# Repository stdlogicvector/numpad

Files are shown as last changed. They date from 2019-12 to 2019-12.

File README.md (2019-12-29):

# NumPad

A custom built 5x4 key numpad with encoders and display.

More Info on this [Reddit Thread](https://www.reddit.com/r/MechanicalKeyboards/comments/e81bfg/custom_built_numpad_with_encoders_and_display/)

## Circuit Board

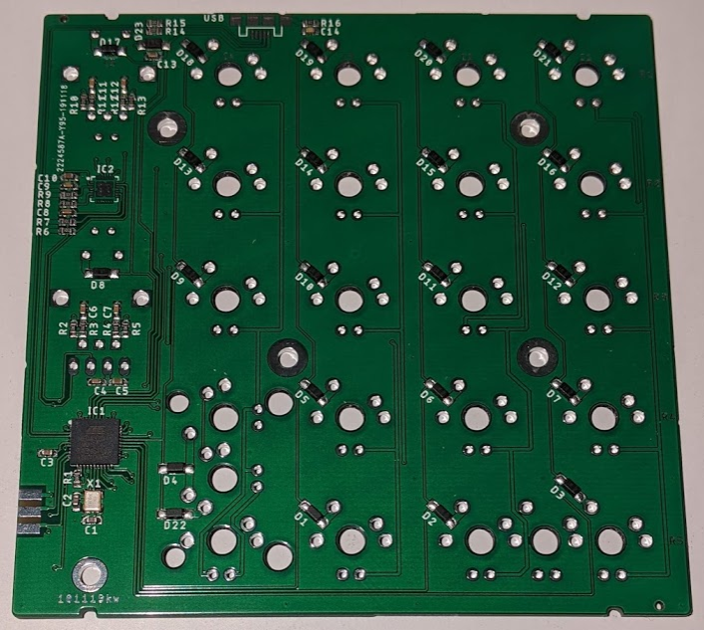
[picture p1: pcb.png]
Populated Circit Board - Bottom Side


The circuit board is designed in Eagle.
For easy manufacturing, the gerber-files and SMT production files are included.

The BOM and SMT placement file (CPL) are formatted for use with JLCPCB.

Apart from the keys, encoders, display, the USB-connector and the LED matrix driver all parts can be populated by JLCPCB.
The schematic contains the LCSC partnumbers in the attributes of each part.

### JLCPCB Configuration

If you want to order PCBs from JLC-PCB with the provided gerber-files,
use the following settings after uploading the zipped gerber folder:

* Layers: 2
* Dimension: 98mm*98mm
* PCB Thickness: 1.6
* PCB Color: Choose what you want
* Impedance: no
* Surface Finish: HASL(with lead) (ENIG is also OK)
* Copper Weight: 1
* Gold Fingers: No
* Material Details: FR4-Standard Tg 130-140C
* Panel By JLCPCB: No
* Flying Probe Test: Fully Test
* Castellated Holes: no
* Different Design: 1
* Remove Order Number: Choose what you want

5 PCBs without assembly cost about 3.60€ or $4.00.

If you want to have the SMT parts populated, choose "SMT Assembly" and select "Bottom Layer".

When asked for the BOM and CPL file, upload the provided files.

Assembly and parts for 5 PCBs costs about 33.30€ or $37.10.

### Keys

All keys compatible with Cherry MX 2 or 3 pin should fit the board.
You can either use a wide 0-key or a normal 0-key and a 00-key.
The Enter-key can also be replaced by two individual keys.

Unfortunately, I forgot to include the option for a standard tall plus-key. Here you have to use two keys.

### Encoders

The encoders a standard rotary encoders, just search ebay/aliexpress/amazon or your local electronics dealer.

### Display

The display is an 0.91" 128x32 SPI OLED module like [this](https://www.ebay.com/itm/312892164528). They are all over ebay and aliexpress.

### Misc Parts

The USB Connector can be found on [Digikey](https://www.digikey.com/short/p12hh9), but you can substitute others with the same pad layout.

The LED Driver is also available on [Digikey](https://www.digikey.com/short/p12hhw).

## QMK Configuration

The folder qmk_config contains the configuration and code to build QMK for the NumPad.
Just put this folder in qmk/keyboards and run

```
make numpad/v1:default
```	
	
## Case

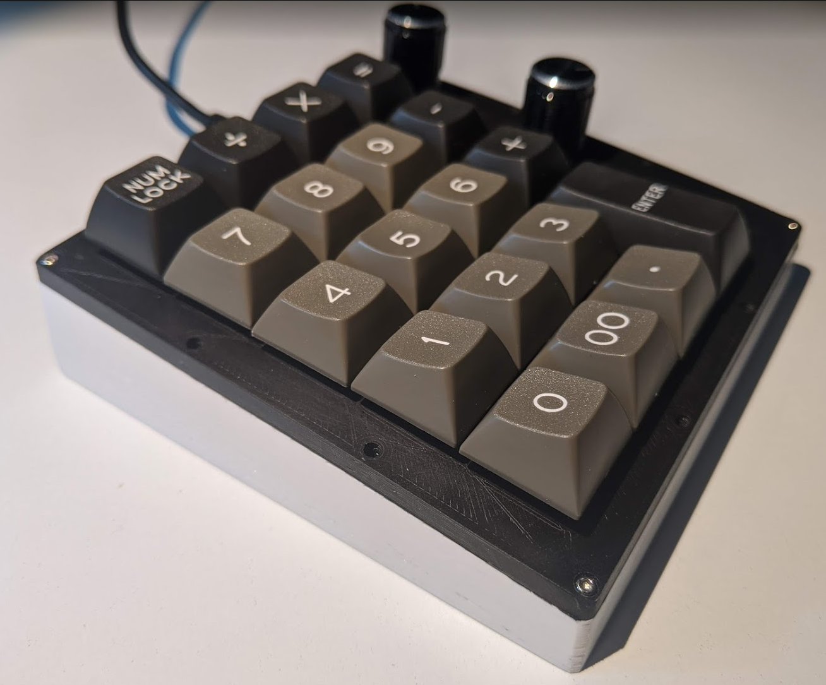
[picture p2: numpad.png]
Numpad with 3D printed case


The case can be 3D printed in two parts.
There are holes for heat-set M3 threaded inserts to hold the PCB and M2 threaded inserts to hold the plate.

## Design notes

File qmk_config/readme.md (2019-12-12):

NumPad
===

NumPad

-=-=-=-=-=-=-=-=-=-=-=-=-=-=-=-

A 18/19/20 key num-pad with 2 rotary encoders and OLED display.

Supports MX switches with LEDs.

Optional "Reset" switch can be used on the PCB.

-=-=-=-=-=-=-=-=-=-=-=-=-=-=-=-

Make example for this keyboard (after setting up your build environment):

    make numpad/v1:default

See [build environment setup](https://docs.qmk.fm/#/getting_started_build_tools) then the [make instructions](https://docs.qmk.fm/#/getting_started_make_guide) for more information.

-=-=-=-=-=-=-=-=-=-=-=-=-=-=-=-

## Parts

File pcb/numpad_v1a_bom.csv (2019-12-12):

Comment | Designator | Footprint | LCSC
1M | R16 | 0603_R | C22935
1N4148W | D1, D2, D3, D4, D5, D6, D7, D8, D9, D10, D11, D12, D13, D14, D15, D16, D17, D18, D19, D20, D21, D22 | SOD-123 | C81598
1u | C3, C5, C10 | 0603_C | C15849
10k | R1, R2, R3, R4, R5, R10, R11, R12, R13 | 0603_R | C25804
10n | C6, C7, C11, C12 | 0603_C | C57112
10n 100V | C14 | 0603_C | C84709
10u | C13 | 0603_C | C19702
12pF | C1, C2 | 0603_C | C38523
16MHz | X1 | SMD-3225_4P | C13738
20k | R6, R7, R8, R9 | 0603_R | C4184
22R | R14, R15 | 0603_R | C23345
100n | C4, C8, C9 | 0603_C | C14663
ATMEGA32U4-MU | IC1 | QFN-44_EP_7x7x0.5P | C112161
B5819W | D23 | SOD-123 | C8598

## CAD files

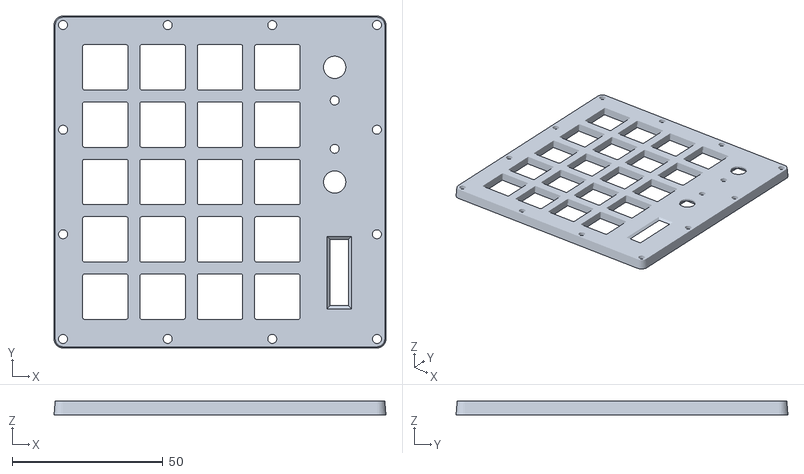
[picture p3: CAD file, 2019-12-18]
case/Cover_4x5.stl
110.0 x 110.0 x 4.50

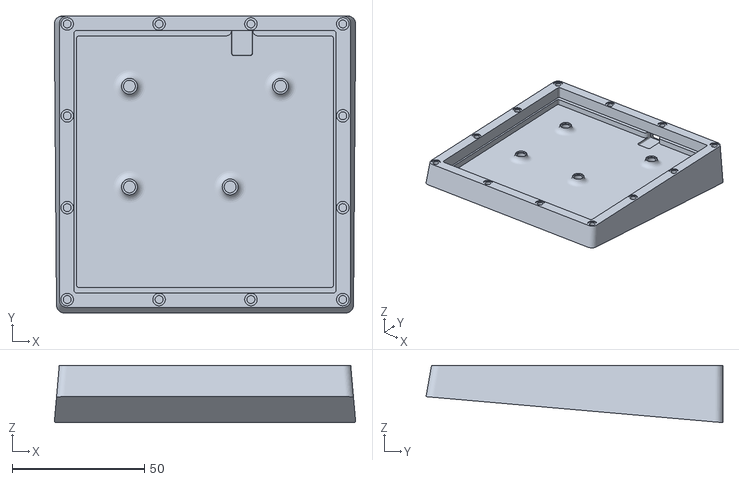
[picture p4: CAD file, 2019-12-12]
case/Case.stl
113.7 x 112.1 x 21.6

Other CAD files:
case/Cover.stl

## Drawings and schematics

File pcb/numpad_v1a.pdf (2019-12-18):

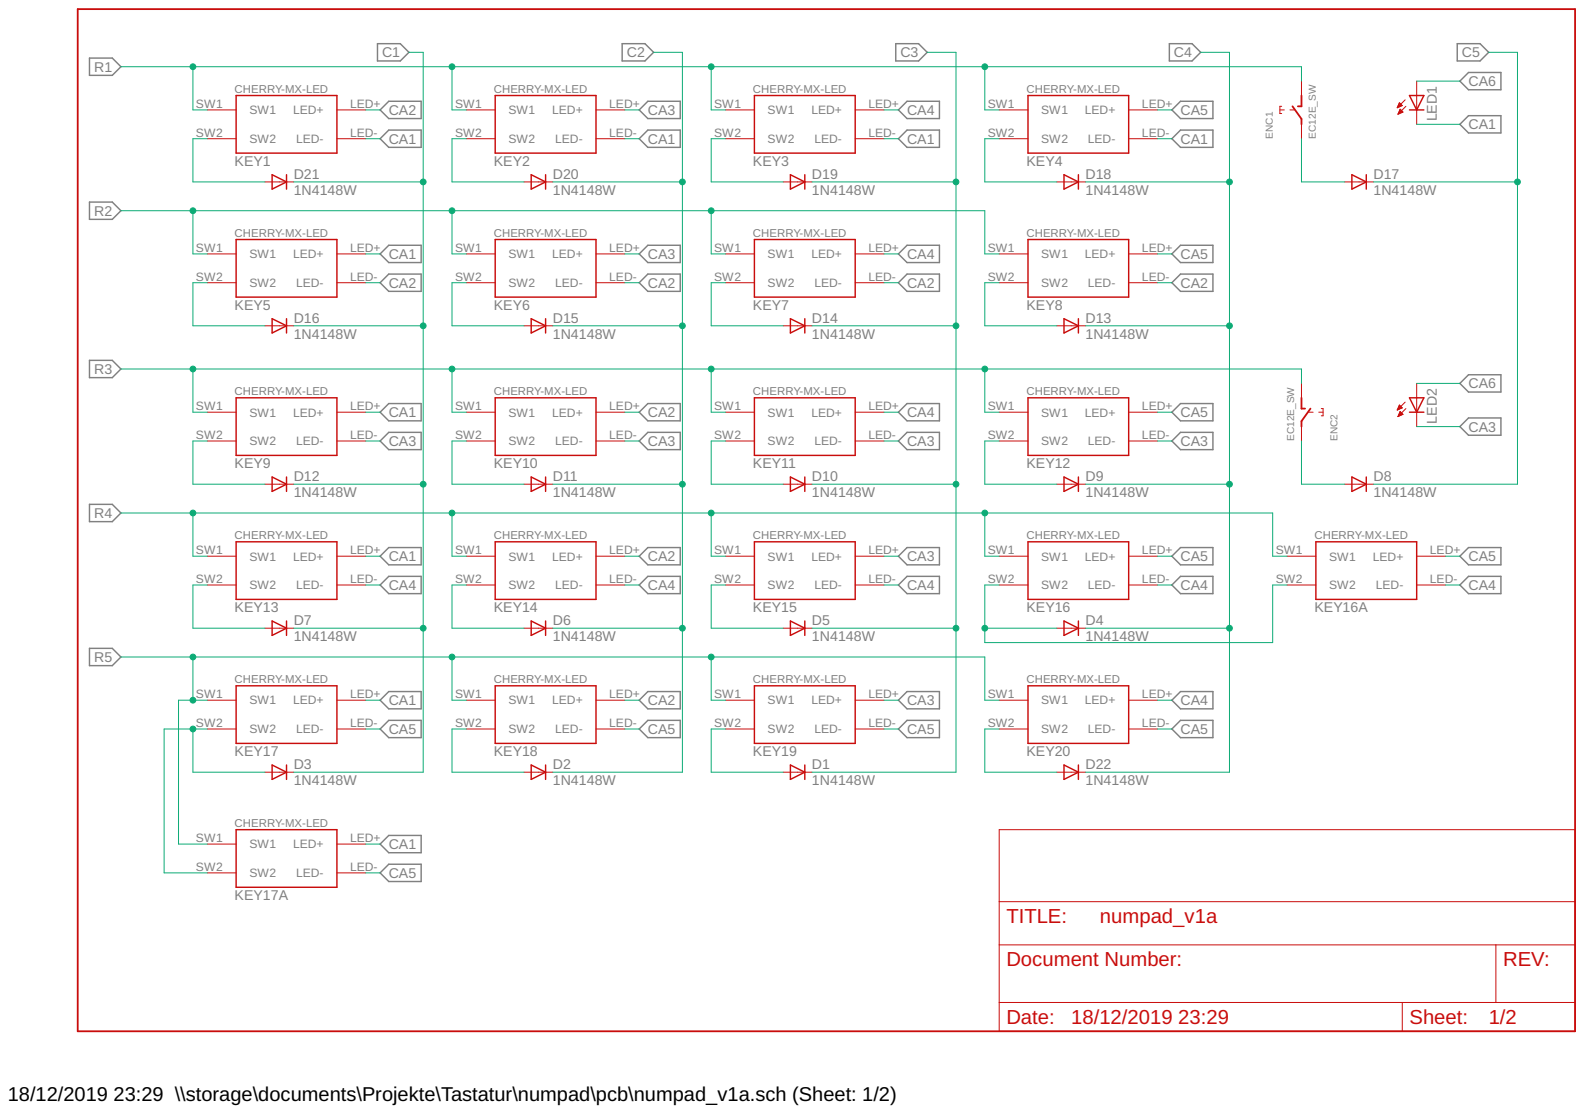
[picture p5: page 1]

Document Number: | REV:

Date: 18/12/2019 23:29 | Sheet: 1/2

18/12/2019 23:29 \\storage\documents\Projekte\Tastatur\numpad\pcb\numpad_v1a.sch (Sheet: 1/2)

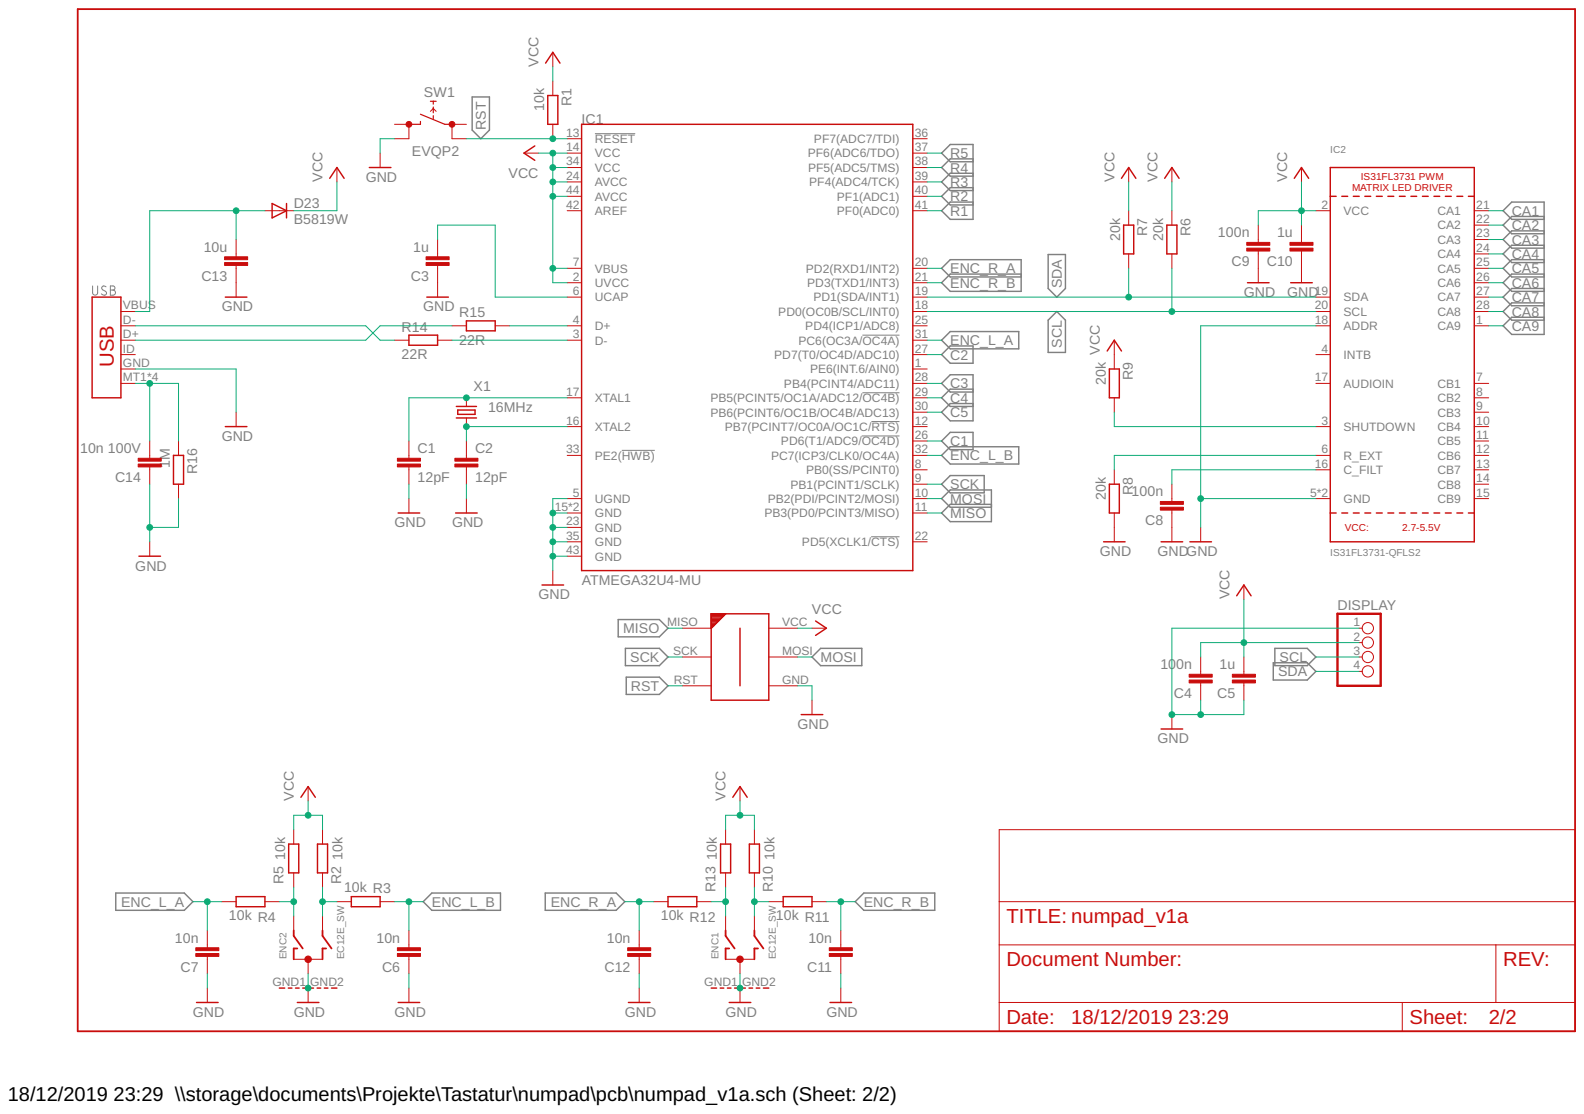
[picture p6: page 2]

18/12/2019 23:29 \\storage\documents\Projekte\Tastatur\numpad\pcb\numpad_v1a.sch (Sheet: 2/2)

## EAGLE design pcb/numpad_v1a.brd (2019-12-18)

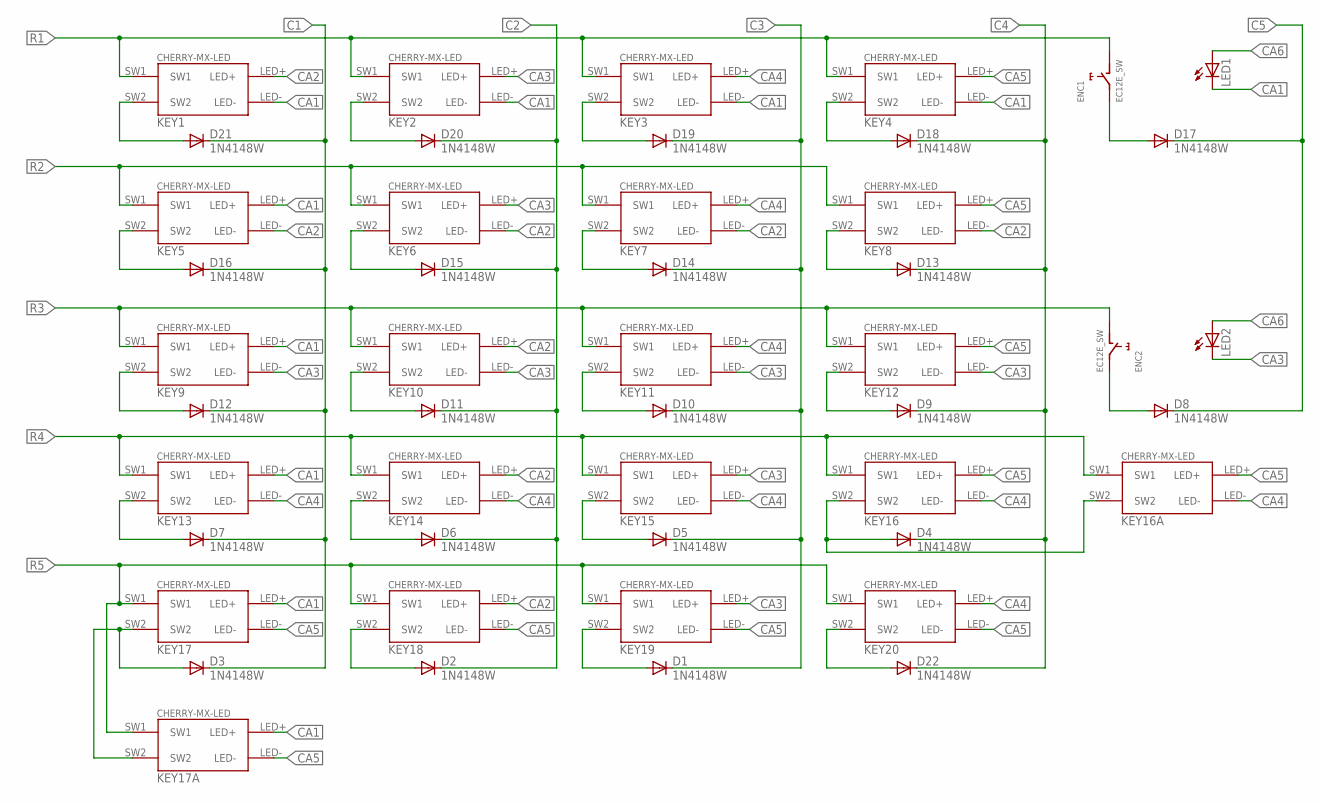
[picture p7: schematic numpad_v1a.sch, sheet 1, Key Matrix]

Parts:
D1, D2, D3, D4, D5, D6, D7, D8, D9, D10, D11, D12, D13, D14, D15, D16, D17, D18, D19, D20, D21, D22: 1N4148W; SOD123; LCSC C81598
ENC1, ENC2: EC12E_SW; ALPS_EC12E_SW
KEY1, KEY2, KEY3, KEY4, KEY5, KEY6, KEY7, KEY8, KEY9, KEY10, KEY11, KEY12, KEY13, KEY14, KEY15, KEY16A, KEY17, KEY18, KEY19, KEY20: CHERRY-MX-LED
KEY16, KEY17A: CHERRY-MX-LED_NOHOLES
LED1, LED2: LED3MM

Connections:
C1: D3.C, D7.C, D12.C, D16.C, D21.C; also elsewhere on the board
C2: D2.C, D6.C, D11.C, D15.C, D20.C; also elsewhere on the board
C3: D1.C, D5.C, D10.C, D14.C, D19.C; also elsewhere on the board
C4: D4.C, D9.C, D13.C, D18.C, D22.C; also elsewhere on the board
C5: D8.C, D17.C; also elsewhere on the board
CA1: KEY1.LED-, KEY2.LED-, KEY3.LED-, KEY4.LED-, KEY5.LED+, KEY9.LED+, KEY13.LED+, KEY17.LED+, KEY17A.LED+, LED1.K (C); also elsewhere on the board
CA2: KEY1.LED+, KEY5.LED-, KEY6.LED-, KEY7.LED-, KEY8.LED-, KEY10.LED+, KEY14.LED+, KEY18.LED+; also elsewhere on the board
CA3: KEY2.LED+, KEY6.LED+, KEY9.LED-, KEY10.LED-, KEY11.LED-, KEY12.LED-, KEY15.LED+, KEY19.LED+, LED2.K (C); also elsewhere on the board
CA4: KEY3.LED+, KEY7.LED+, KEY11.LED+, KEY13.LED-, KEY14.LED-, KEY15.LED-, KEY16.LED-, KEY16A.LED-, KEY20.LED+; also elsewhere on the board
CA5: KEY4.LED+, KEY8.LED+, KEY12.LED+, KEY16.LED+, KEY16A.LED+, KEY17.LED-, KEY17A.LED-, KEY18.LED-, KEY19.LED-, KEY20.LED-; also elsewhere on the board
CA6: LED1.A, LED2.A; also elsewhere on the board
unnamed: D21.A, KEY1.SW2
unnamed: D16.A, KEY5.SW2
unnamed: D12.A, KEY9.SW2
unnamed: D7.A, KEY13.SW2
unnamed: D15.A, KEY6.SW2
unnamed: D20.A, KEY2.SW2
unnamed: D11.A, KEY10.SW2
unnamed: D6.A, KEY14.SW2
unnamed: D5.A, KEY15.SW2
unnamed: D10.A, KEY11.SW2
unnamed: D14.A, KEY7.SW2
unnamed: D19.A, KEY3.SW2
unnamed: D8.A, ENC2.E (2)
unnamed: D17.A, ENC1.E (2)
unnamed: D3.A, KEY17.SW2, KEY17A.SW2
unnamed: D2.A, KEY18.SW2
unnamed: D1.A, KEY19.SW2
unnamed: D4.A, KEY16.SW2, KEY16A.SW2
unnamed: D9.A, KEY12.SW2
unnamed: D13.A, KEY8.SW2
unnamed: D18.A, KEY4.SW2
unnamed: D22.A, KEY20.SW2
R1: ENC1.D (1), KEY1.SW1, KEY2.SW1, KEY3.SW1, KEY4.SW1; also elsewhere on the board
R2: KEY5.SW1, KEY6.SW1, KEY7.SW1, KEY8.SW1; also elsewhere on the board
R3: ENC2.D (1), KEY9.SW1, KEY10.SW1, KEY11.SW1, KEY12.SW1; also elsewhere on the board
R4: KEY13.SW1, KEY14.SW1, KEY15.SW1, KEY16.SW1, KEY16A.SW1; also elsewhere on the board
R5: KEY17.SW1, KEY17A.SW1, KEY18.SW1, KEY19.SW1, KEY20.SW1; also elsewhere on the board

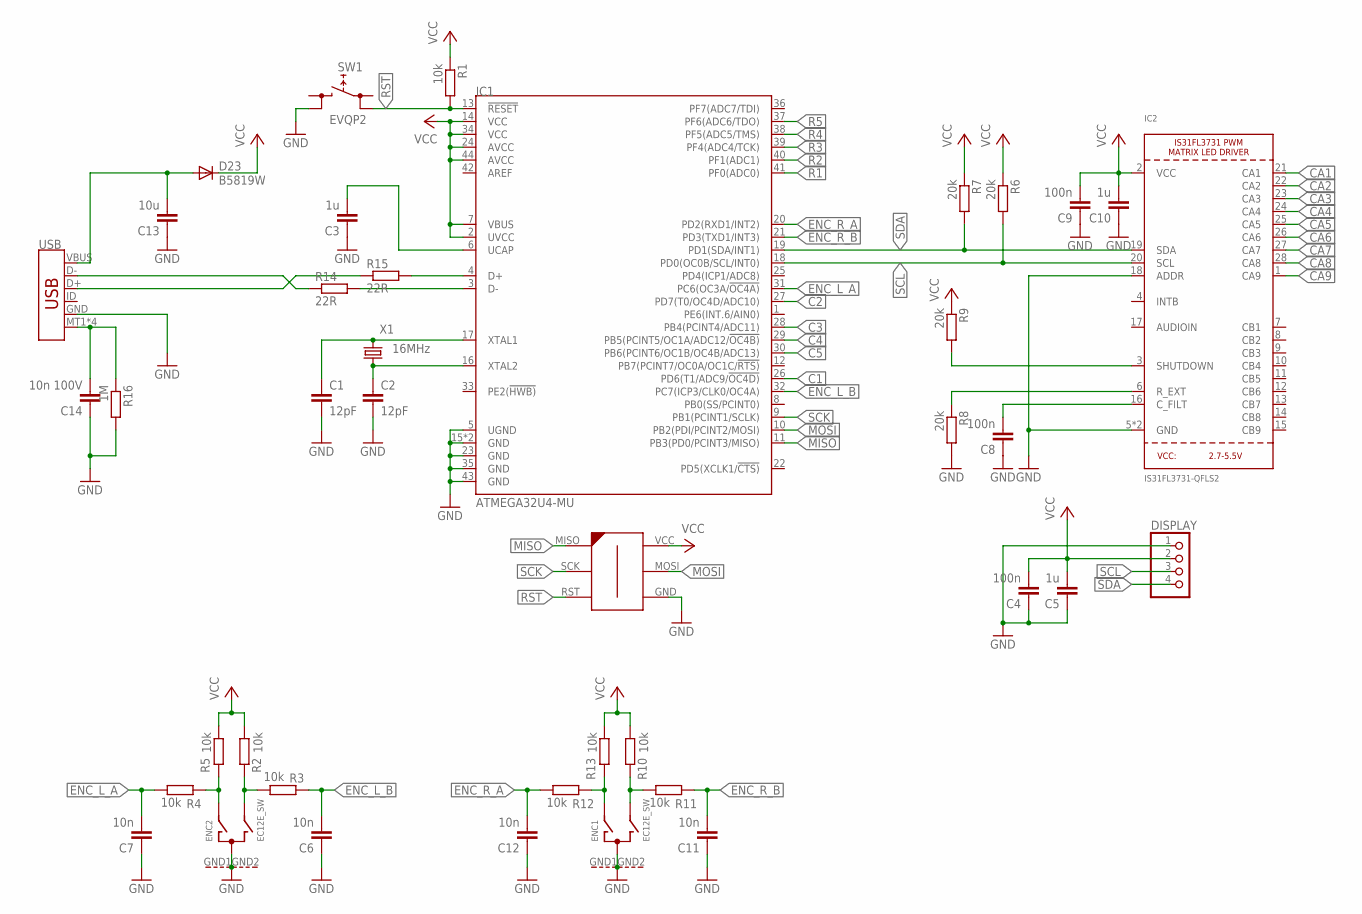
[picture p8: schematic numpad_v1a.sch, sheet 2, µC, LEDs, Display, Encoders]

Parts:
C1, C2: 12pF; C0603; LCSC C38523
C3, C5, C10: 1u; C0603; LCSC C15849
C4, C8, C9: 100n; C0603; LCSC C14663
C6, C7, C11, C12: 10n; C0603; LCSC C57112
C13: 10u; C0603; LCSC C19702
C14: 10n 100V; C0603; LCSC C84709
D23: B5819W; SOD123; LCSC C8598
DISPLAY: PINHD-1X4; 1X04
ENC1, ENC2: EC12E_SW; ALPS_EC12E_SW
IC1: ATMEGA32U4-MU; QFN44G-0.5-7X7MM; LCSC C112161
IC2: IS31FL3731-QFLS2; QFN28_4MM_0.4MM
ISP: AVR-ISP-6-EDGE; 6PAD_ISP
R1, R2, R3, R4, R5, R10, R11, R12, R13: 10k; R0603; LCSC C25804
R6, R7, R8, R9: 20k; R0603; LCSC C4184
R14, R15: 22R; R0603; LCSC C23345
R16: 1M; R0603; LCSC C22935
SW1: EVQP2; FARNELL 2079559
USB: USB_MICRO-B_SMT; USB-MICROB; DIGIKEY 609-4052-1-ND
X1: 16MHz; 3.2X2.5_KX-7; LCSC C13738

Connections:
C1: IC1.26 (PD6(T1/ADC9/!OC4D)); also elsewhere on the board
C2: IC1.27 (PD7(T0/OC4D/ADC10)); also elsewhere on the board
C3: IC1.28 (PB4(PCINT4/ADC11)); also elsewhere on the board
C4: IC1.29 (PB5(PCINT5/OC1A/ADC12/!OC4B)); also elsewhere on the board
C5: IC1.30 (PB6(PCINT6/OC1B/OC4B/ADC13)); also elsewhere on the board
CA1: IC2.21 (CA1); also elsewhere on the board
CA2: IC2.22 (CA2); also elsewhere on the board
CA3: IC2.23 (CA3); also elsewhere on the board
CA4: IC2.24 (CA4); also elsewhere on the board
CA5: IC2.25 (CA5); also elsewhere on the board
CA6: IC2.26 (CA6); also elsewhere on the board
CA7: IC2.27 (CA7)
CA8: IC2.28 (CA8)
CA9: IC2.1 (CA9)
ENC_L_A: C7.2, IC1.31 (PC6(OC3A/!OC4A)), R4.1
ENC_L_B: C6.2, IC1.32 (PC7(ICP3/CLK0/OC4A)), R3.2
ENC_R_A: C12.2, IC1.20 (PD2(RXD1/INT2)), R12.1
ENC_R_B: C11.2, IC1.21 (PD3(TXD1/INT3)), R11.2
GND: C1.2, C2.2, C3.1, C4.1, C5.1, C6.1, C7.1, C8.1, C9.1, C10.1, C11.1, C12.1, C13.1, C14.1, DISPLAY.1, ENC1.C, ENC1.GND1 (G), ENC1.GND2 (G), ENC2.C, ENC2.GND1 (G), ENC2.GND2 (G), IC1.5 (UGND), IC1.15 (GND), IC1.23 (GND), IC1.35 (GND), IC1.43 (GND), IC1.TAB (GND), IC2.5 (GND), IC2.18 (ADDR), IC2.THERMAL (GND), ISP.GND, R8.2, R16.2, SW1.2 (1), USB.GND
MISO: IC1.11 (PB3(PD0/PCINT3/MISO)), ISP.MISO
MOSI: IC1.10 (PB2(PDI/PCINT2/MOSI)), ISP.MOSI
unnamed: IC1.4 (D+), R15.2
unnamed: IC1.3 (D-), R14.2
unnamed: R14.1, USB.D-
unnamed: R15.1, USB.D+
unnamed: C1.1, IC1.17 (XTAL1), X1.3 (2)
unnamed: C13.2, D23.A, USB.VBUS
unnamed: C2.1, IC1.16 (XTAL2), X1.1
unnamed: C3.2, IC1.6 (UCAP)
unnamed: IC2.6 (R_EXT), R8.1
unnamed: C8.2, IC2.16 (C_FILT)
unnamed: IC2.3 (SHUTDOWN), R9.2
unnamed: ENC2.A, R4.2, R5.2
unnamed: ENC1.A, R12.2, R13.2
unnamed: ENC2.B, R2.2, R3.1
unnamed: ENC1.B, R10.2, R11.1
unnamed: C14.2, R16.1, USB.MT1 (SHIELD), USB.MT2 (SHIELD), USB.P$1 (SHIELD), USB.P$2 (SHIELD)
R1: IC1.41 (PF0(ADC0)); also elsewhere on the board
R2: IC1.40 (PF1(ADC1)); also elsewhere on the board
R3: IC1.39 (PF4(ADC4/TCK)); also elsewhere on the board
R4: IC1.38 (PF5(ADC5/TMS)); also elsewhere on the board
R5: IC1.37 (PF6(ADC6/TDO)); also elsewhere on the board
RST: IC1.13 (!RESET), ISP.RST, R1.2, SW1.3 (0)
SCK: IC1.9 (PB1(PCINT1/SCLK)), ISP.SCK
SCL: DISPLAY.3, IC1.18 (PD0(OC0B/SCL/INT0)), IC2.20 (SCL), R6.2
SDA: DISPLAY.4, IC1.19 (PD1(SDA/INT1)), IC2.19 (SDA), R7.2
VCC: C4.2, C5.2, C9.2, C10.2, D23.C, DISPLAY.2, IC1.2 (UVCC), IC1.7 (VBUS), IC1.14 (VCC), IC1.24 (AVCC), IC1.34 (VCC), IC1.44 (AVCC), IC2.2 (VCC), ISP.VCC, R1.1, R2.1, R5.1, R6.1, R7.1, R9.1, R10.1, R13.1

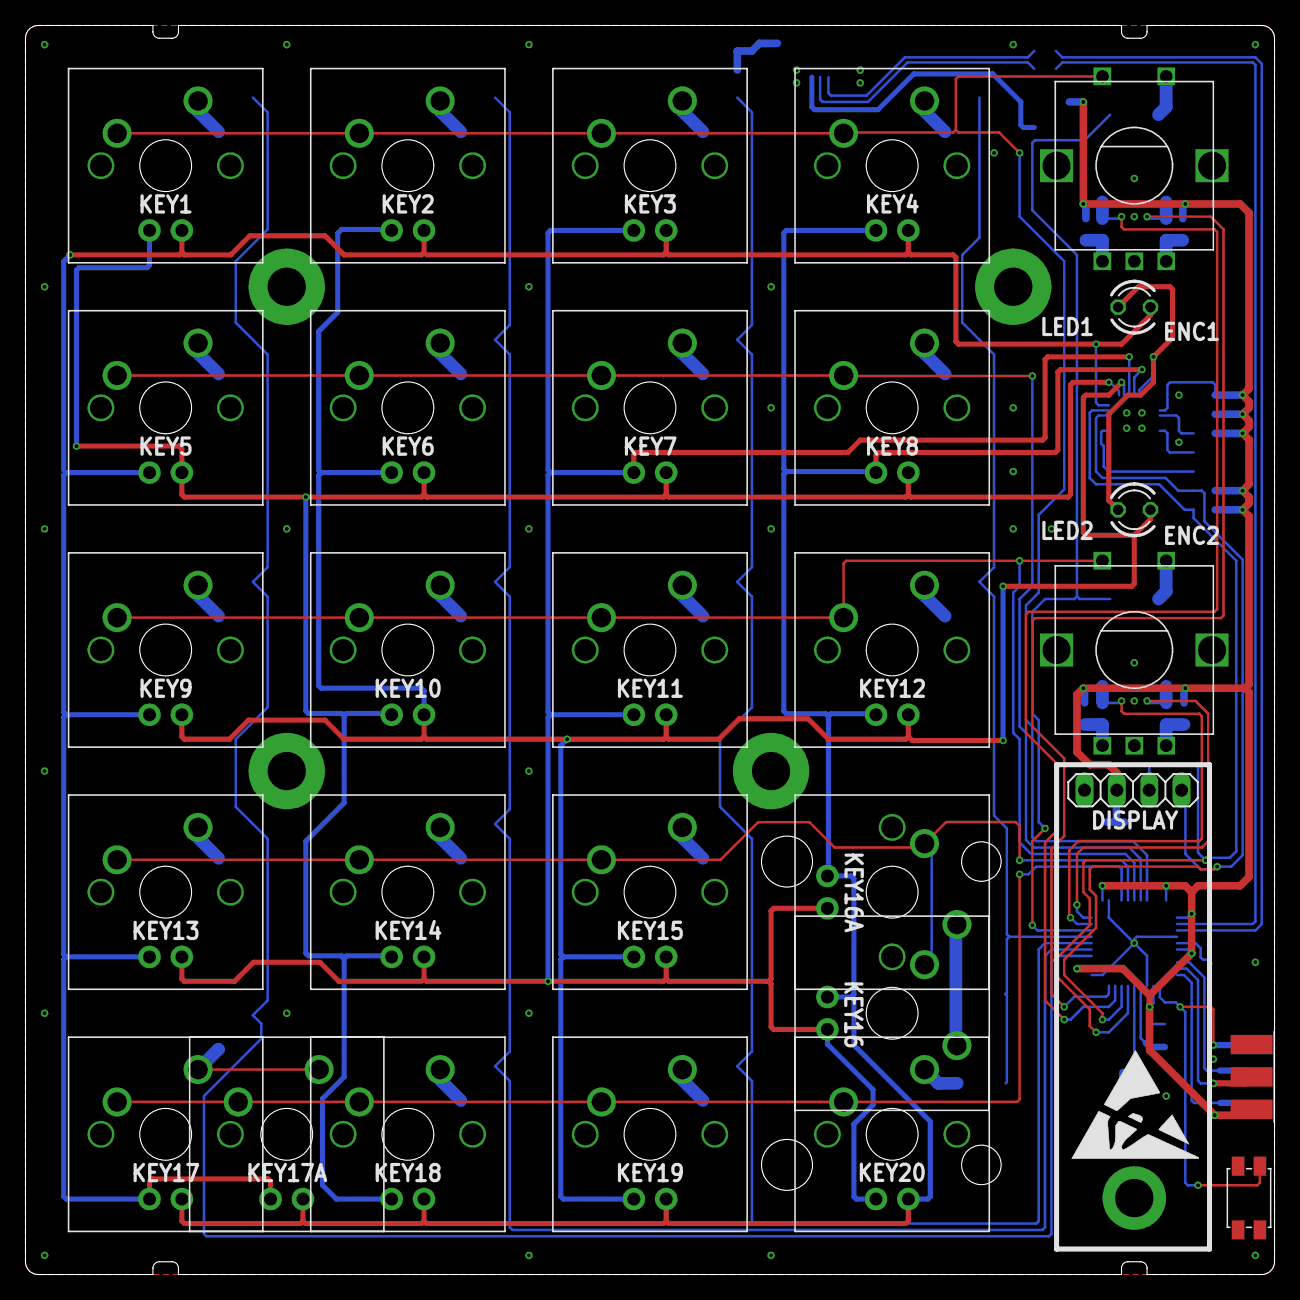
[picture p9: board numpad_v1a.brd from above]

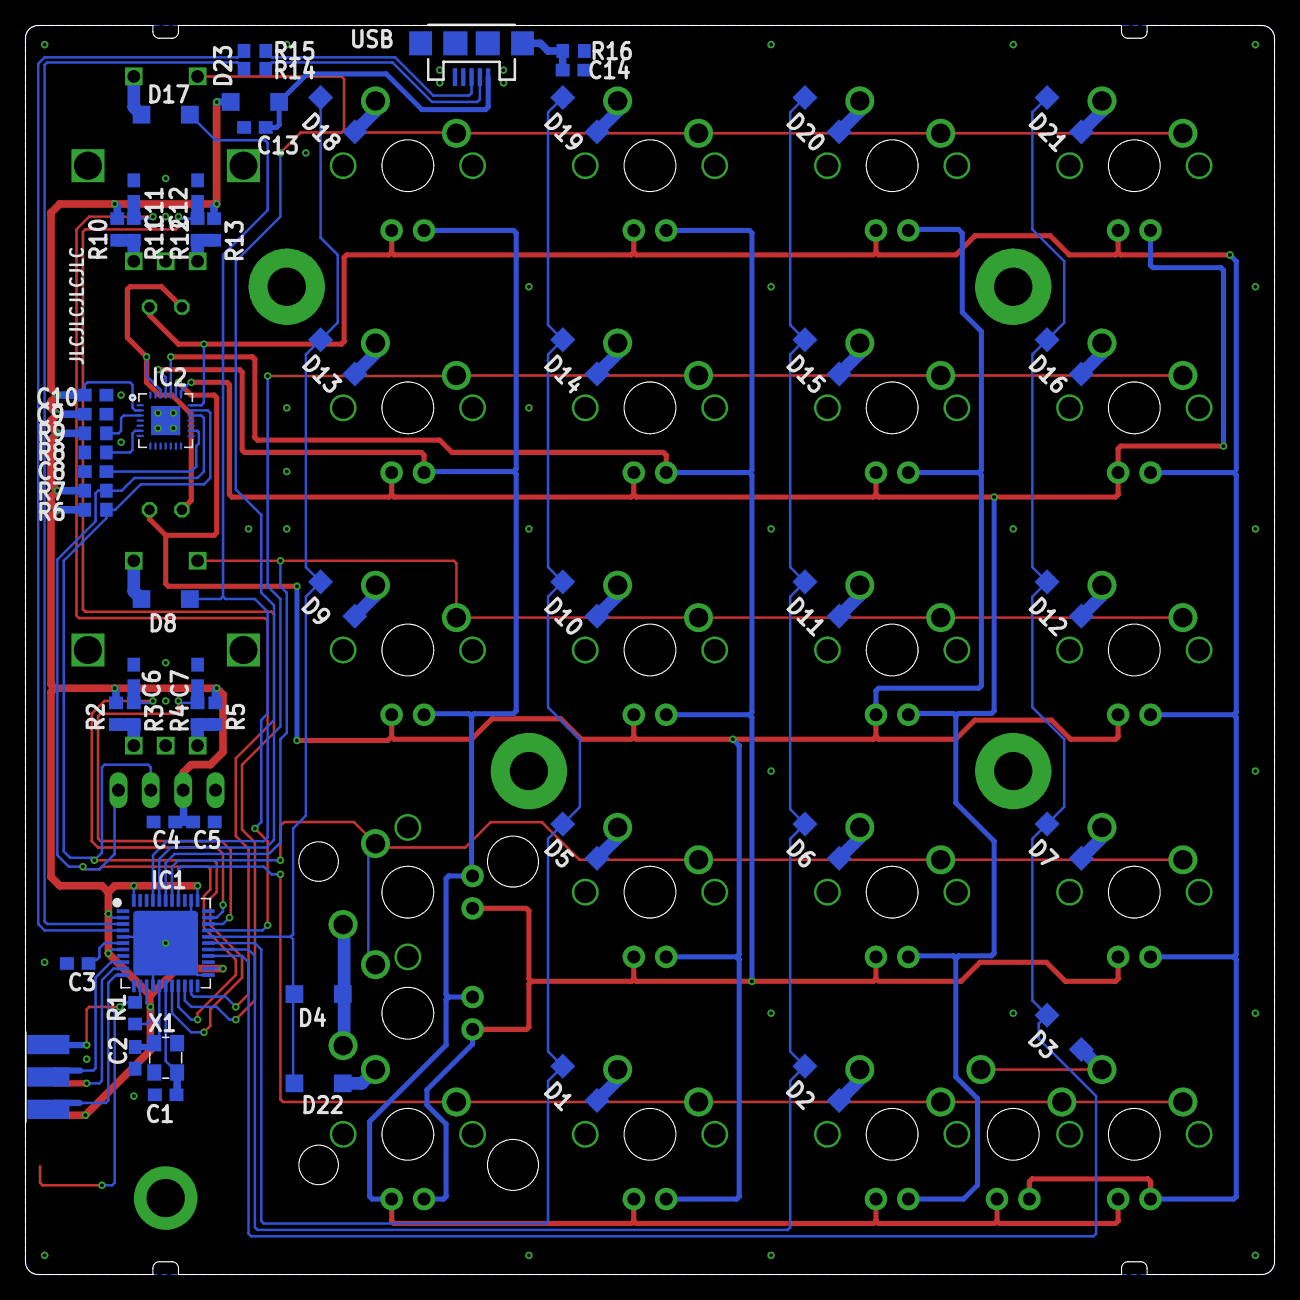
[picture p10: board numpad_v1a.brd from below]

Board: 2 copper layers, 98.0 x 98.0 mm, 87 parts (58 on the bottom side), 66 nets.

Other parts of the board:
U$1: ESD_10.00

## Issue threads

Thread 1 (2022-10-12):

Hot-swappable sockets

letshin, 2022-10-12:
Doesn't look like it but I wanted to check with you if there are traces for Hot-swappable-Socket-CPG151101S11-Mechanical-Keyboard on your PCB? Thanks.

stdlogicvector, 2022-11-23:
Sorry, there aren't any traces for those. Maybe in a future design :)

Closed 2022-11-23.

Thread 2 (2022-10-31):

Flashing firmware and bootloader

letshin, 2022-10-31:
I can't seem to get the bootloader to flash and to get DFU working. I've flashed this with avrdude but can't get a USB device detected:

avrdude.exe -p atmega32u4 -c stk500v1 -b 19200 -U flash:w:"ATMega32U4-usbdevice_dfu-1_0_0.hex":i -P COM7 -U lfuse:w:0xFE:m	-U hfuse:w:0x99:m	-U efuse:w:0xFF:m

any advice please?

stdlogicvector, 2022-11-23:
I didn't have notifications turned on, so I missed your question. It seems like you got it working, what was the problem?

letshin, 2022-11-27:
A couple of things, hardware-wise the v supply was swapped around by the fab factory, then the datasheet for the sheet said that the bootloader wasn't flashed but that's actually an error as they come pre-flashed.

Other errors were because the USB wasn't soldered properly but I finally figured out how to solder it after some tries - messed up a couple of boards but got there in the end.

Closed 2022-11-10.

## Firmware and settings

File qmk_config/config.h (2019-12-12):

/*
Copyright 2019 KW

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
You should have received a copy of the GNU General Public License
along with this program.  If not, see <http://www.gnu.org/licenses/>.
*/

#ifndef CONFIG_H
#define CONFIG_H

#include "config_common.h"

/* USB Device descriptor parameter */
#define VENDOR_ID       0xFEED
#define PRODUCT_ID      0x9001
#define MANUFACTURER    KW
#define PRODUCT         NumPad
#define DESCRIPTION     Numpad with Encoders

/* key matrix size */
#define MATRIX_ROWS 5
#define MATRIX_COLS 5

/* define if matrix has ghost */
//#define MATRIX_HAS_GHOST

/* Set 0 if debouncing isn't needed */
#define DEBOUNCE 5

/* Combo */
#define	TAPPING_TERM	200

/* Mechanical locking support. Use KC_LCAP, KC_LNUM or KC_LSCR instead in keymap */
//#define LOCKING_SUPPORT_ENABLE
/* Locking resynchronize hack */
//#define LOCKING_RESYNC_ENABLE

#define LED_DRIVER_COUNT		1
#define LED_DRIVER_LED_COUNT	22
#define LED_DRIVER_ADDR_1		0b1110100	// 0x74 // AD-Pin to GND

#define BACKLIGHT_LEVELS 		8

#ifdef SUBPROJECT_v1
    #include "v1/config.h"
#endif

#endif

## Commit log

2019-12-12 First Revision
    [Case.stl, Cover.stl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]
2019-12-12 add(pcb): Schematic PDF
    [Case.CATPart, Cover.CATPart, Numpad.CATProduct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]
2019-12-12 fix(misc):Remove tmp files
    [numpad_v1.brd, numpad_v1.sch, numpad_v1_bom.csv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]
2019-12-12 fix(pcb):Remove old gerbers
    [numpad_v1.GBL, numpad_v1.GBO, numpad_v1.GBP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]
2019-12-12 fix(pcb): Both sheets in schematic
2019-12-12 add(gitignore): Added gitignore
    [Case.CATPart, Cover.CATPart, Numpad.CATProduct]
2019-12-18 add(cover_4x5): Added 20-key cover
    [Cover_4x5.stl]
2019-12-18 fix(schematic): Corrected LED driver part number
    [numpad_v1a.brd, numpad_v1a.sch]

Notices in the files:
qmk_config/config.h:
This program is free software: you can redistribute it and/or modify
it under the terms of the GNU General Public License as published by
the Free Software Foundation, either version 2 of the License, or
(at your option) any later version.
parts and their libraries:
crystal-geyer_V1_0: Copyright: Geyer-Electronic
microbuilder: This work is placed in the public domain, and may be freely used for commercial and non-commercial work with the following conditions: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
